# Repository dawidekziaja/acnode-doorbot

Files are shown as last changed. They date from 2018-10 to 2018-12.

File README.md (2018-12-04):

# acnode-doorbot
A board designed to be used for ACNode and Doorbot at London Hackspace
# Board View and 3D Render
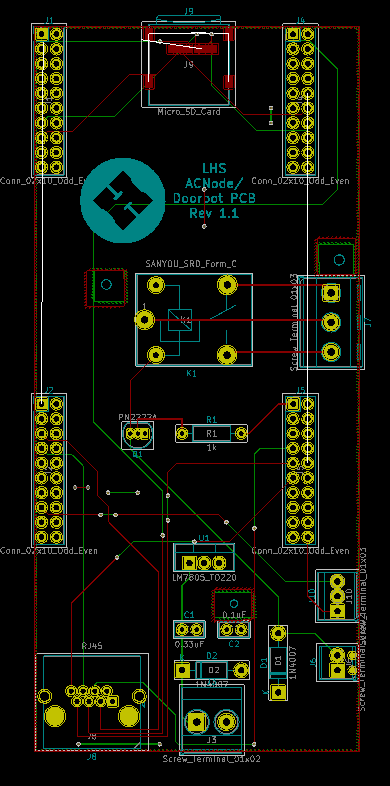
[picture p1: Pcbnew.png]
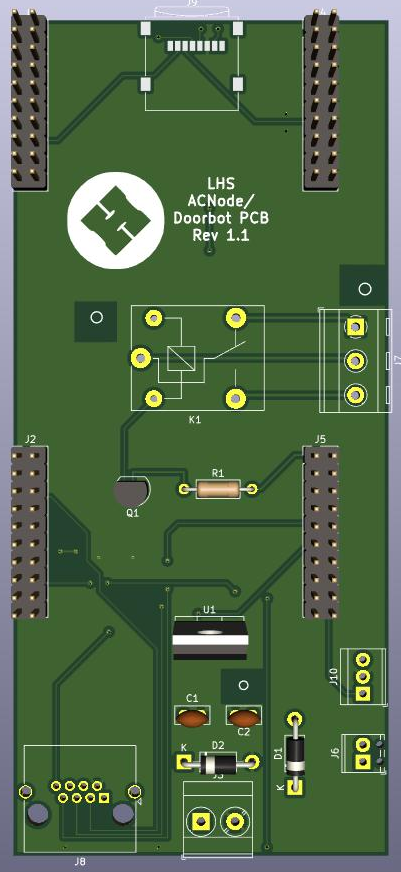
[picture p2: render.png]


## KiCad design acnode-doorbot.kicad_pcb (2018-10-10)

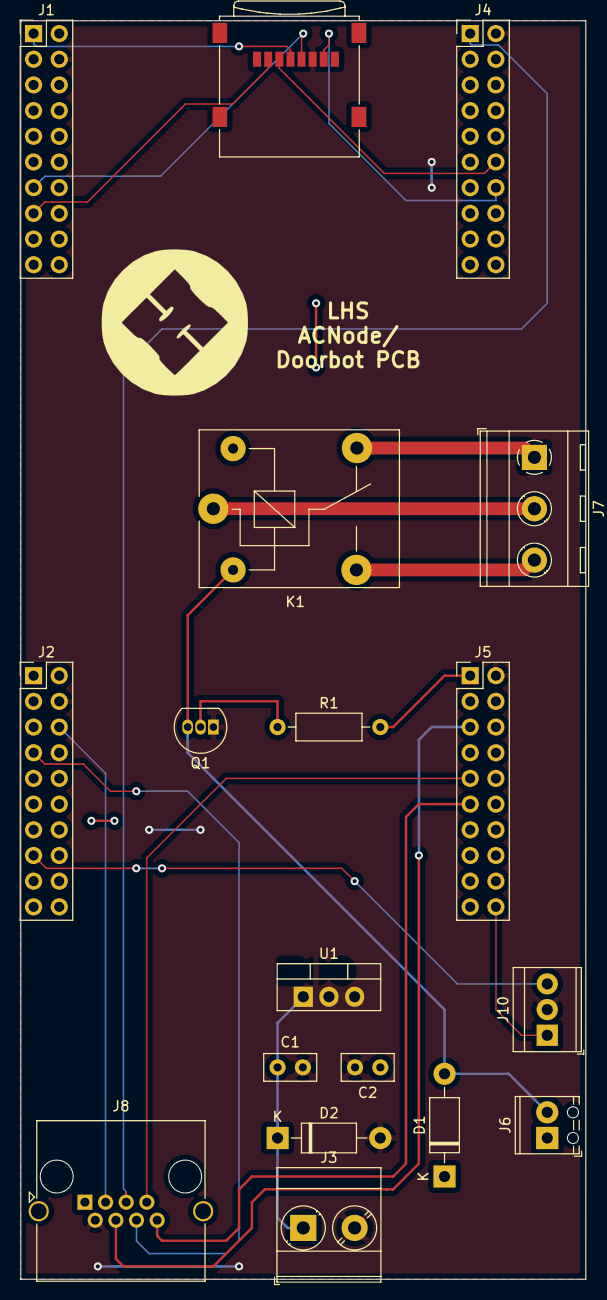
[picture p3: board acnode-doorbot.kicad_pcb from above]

Board: 2 copper layers, 55.9 x 124.5 mm, 18 parts (0 on the bottom side), 23 nets.

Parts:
C1: 0.33uF; C_Disc_D5.0mm_W2.5mm_P2.50mm
C2: 0.1uF; C_Disc_D5.0mm_W2.5mm_P2.50mm
D1, D2: 1N4007; D_DO-41_SOD81_P10.16mm_Horizontal
J1, J2, J4, J5: Conn_02x10_Odd_Even; PinHeader_2x10_P2.54mm_Vertical
J3: Screw_Terminal_01x02; TerminalBlock_Phoenix_MKDS-3-2-5.08_1x02_P5.08mm_Horizontal
J6: Screw_Terminal_01x02; TerminalBlock_Phoenix_MPT-0,5-2-2.54_1x02_P2.54mm_Horizontal
J7: Screw_Terminal_01x03; TerminalBlock_RND_205-00288_1x03_P5.08mm_Horizontal
J8: RJ45; RJ45_Amphenol_RJHSE5380
J9: Micro_SD_Card; microSD_HC_Wuerth_693072010801
J10: Screw_Terminal_01x03; TerminalBlock_TE_282834-3_1x03_P2.54mm_Horizontal
K1: SANYOU_SRD_Form_C; Relay_SPDT_SANYOU_SRD_Series_Form_C
Q1: PN2222A; TO-92_Inline
R1: 1k; R_Axial_DIN0207_L6.3mm_D2.5mm_P10.16mm_Horizontal
U1: LM7805_TO220; TO-220-3_Vertical

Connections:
3.3V: J1.1, J2.1, J9.4
5V: C2.1, D1.1, J1.2, J2.2, J6.1, J8.1, K1.5, U1.3
12V: C1.1, D2.1, J3.1, U1.1
GND: C1.2, C2.2, D2.2, J1.4, J2.4, J3.2, J4.2, J5.2, J8.2, J9.6, J10.2, Q1.1, U1.2
unnamed: D1.2, J6.2, K1.2, Q1.3
unnamed: J7.1, K1.4
unnamed: J7.2, K1.1
unnamed: J7.3, K1.3
unnamed: Q1.2, R1.1
PB_4: J2.6, J8.3
PC_7: J1.15, J9.2
PD_0: J4.14, J9.7
PD_1: J4.12, J9.3
PD_3: J1.13, J9.5
PF_1: J4.1, J8.5
PG_1: J5.1, R1.2
PK_5: J5.5, J8.4
PM_1: J5.9, J8.7
PM_2: J5.11, J8.8
PM_6: J5.20, J10.1
PP_1: J2.7, J8.6
PP_4: J2.15, J10.3
RST: J4.10, J5.10

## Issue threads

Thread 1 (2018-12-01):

Incorrect pinouts (Red LED,Reader TXD)

zymurgic, 2018-12-01:
Raising an issue here so we document the issues on the board, even if we do a software workaround instead of mod wire. Probably mod wire, since UART ports can't be remapped.

- Red LED (RJ45 BLUE pin 4) should connect to PM_0 on the Launchpad, not PK5
- Reader TXD (RJ45 WHITE/GREEN pin 3)/Launchpad RXD PP0 not PB4

dawidekziaja, 2018-12-02:
Fixed in 227654a

Closed 2018-12-02.

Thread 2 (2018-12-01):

Cosmetic layout issue

zymurgic, 2018-12-01:
RJ45 socket needs rotating 180 degrees.

dawidekziaja, 2018-12-02:
Fixed in 227654a

Closed 2018-12-02.

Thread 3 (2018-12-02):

Mounting holes go through GND and 5V planes

dawidekziaja, 2018-12-02:
Creates a short if metallic screws are used

Closed 2018-12-02.
